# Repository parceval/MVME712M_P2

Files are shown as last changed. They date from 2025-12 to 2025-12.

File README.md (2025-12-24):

# MVME712M P2 Adapter Board

An open-source hardware replacement for the **Motorola MVME712M P2 Adapter**.

This board is designed to interface with Motorola VME CPU modules (such as the MVME147, MVME162, MVME167, and MVME177 series) to provide the necessary signals for the **MVME712M Transition Module**.

## Overview

The MVME712M P2 Adapter is a small passive board that plugs directly into the **P2 connector** on the VME backplane behind the CPU module. It breaks out the SCSI, Serial, and Centronics signals to a 50-pin header (or specific cable) that then connects to the MVME712M bulkhead/transition module.

This repository contains the KiCad design files to manufacture a modern replacement for the original Motorola part, which is often difficult to find or expensive on the used market.

## Hardware Features

* **Form Factor:** Standard VME P2 adapter dimensions.
* **Connectors:** * 96-pin DIN 41612 (Connector for VME P2 backplane).
* High-density or IDC headers for connection to the MVME712M transition board.

* **Compatibility:** Designed for use with Motorola MVME modules and the MVME712 series transition boards.
* **Passive Design:** No active components required; uses direct signal routing according to original Motorola specifications.

## Project Structure

```text
├── gerber/    # Gerbers, Drill files
└── docs/      # Pinout diagrams and reference manuals

```

## Compatibility List

This adapter is typically required for the following Motorola CPU boards when using an MVME712M transition module:

* MVME147
* MVME162 / MVME162P
* MVME167
* MVME172
* MVME177

## Usage

1. **Fabrication:** Use the provided Gerber files in the `Manufacturing/` folder to order PCBs (standard 1.6mm FR4, 1oz copper is sufficient).
2. **Assembly:** Solder the 96-pin DIN 41612 connector (Female/Socket) and the appropriate shrouded headers.
3. **Installation:** * Power down the VME chassis.
* Plug the adapter onto the **P2 pins** on the back of the backplane, directly behind your CPU module.
* Connect the internal ribbon cable from the adapter to your MVME712M transition module.

## License

This project is released under the [CERN Open Hardware Licence](https://cern-ohl.web.cern.ch/)

## Disclaimer

This is a community-driven project. While every effort has been made to ensure accuracy based on original documentation, use this hardware at your own risk. The author is not responsible for any damage to vintage VME equipment.

---

*Created by [parceval*](https://github.com/parceval)

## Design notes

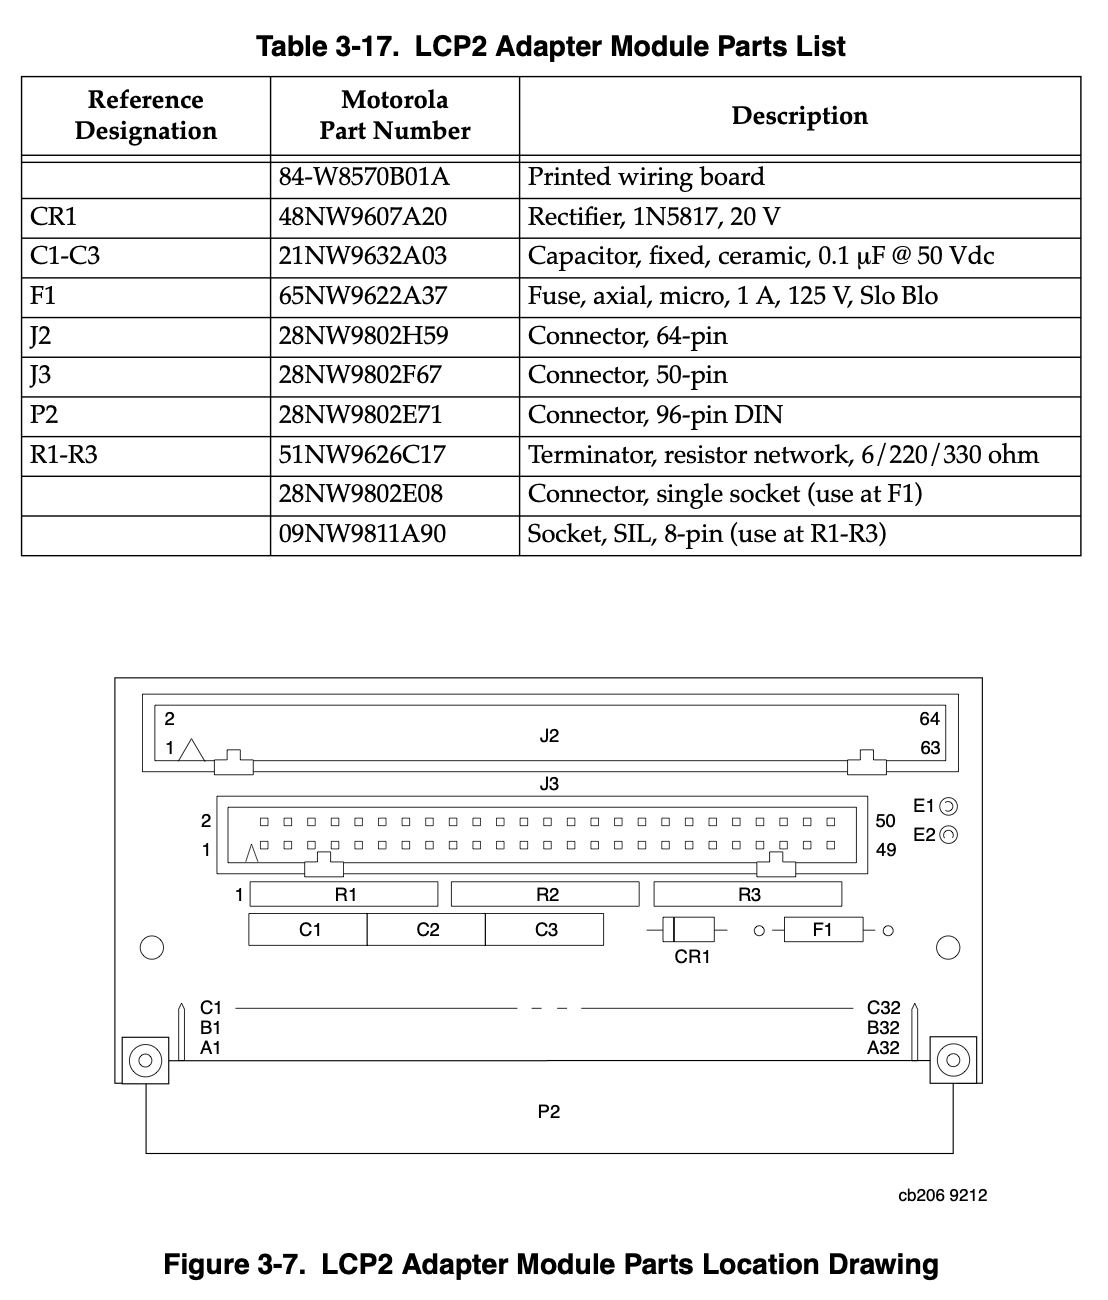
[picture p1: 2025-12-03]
docs/Screenshot_2025-11-25_at_12.06.32.png

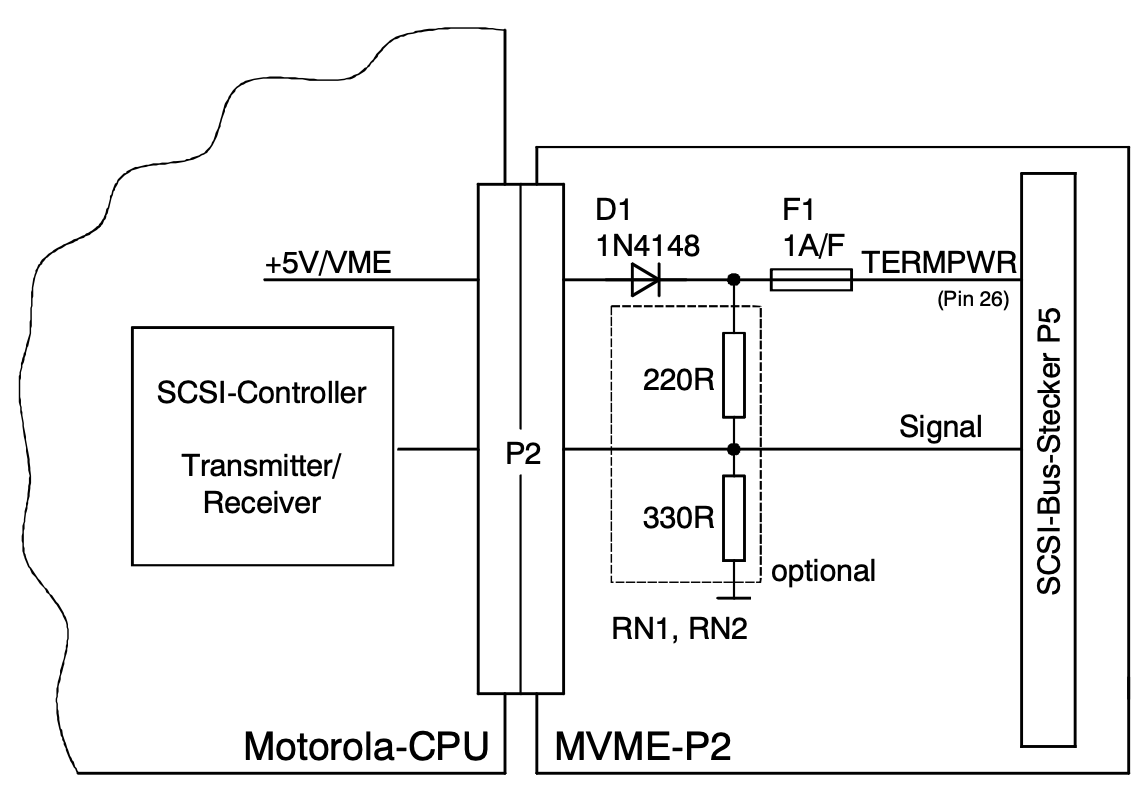
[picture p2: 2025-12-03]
docs/Screenshot_2025-11-25_at_11.56.40.png

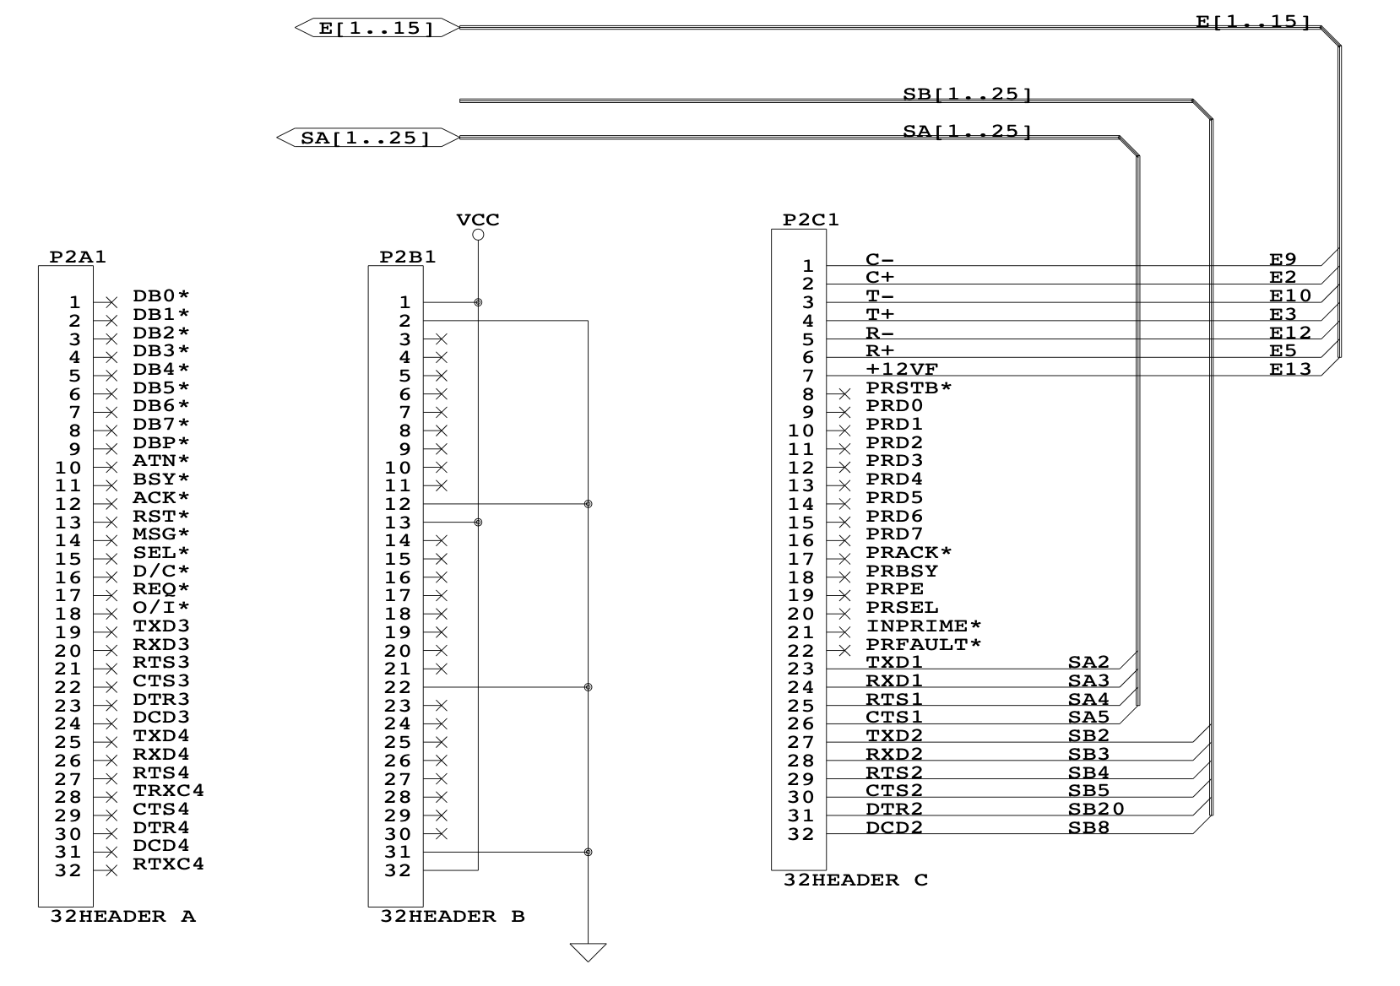
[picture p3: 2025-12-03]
docs/Screenshot_2025-11-25_at_12.11.03.png

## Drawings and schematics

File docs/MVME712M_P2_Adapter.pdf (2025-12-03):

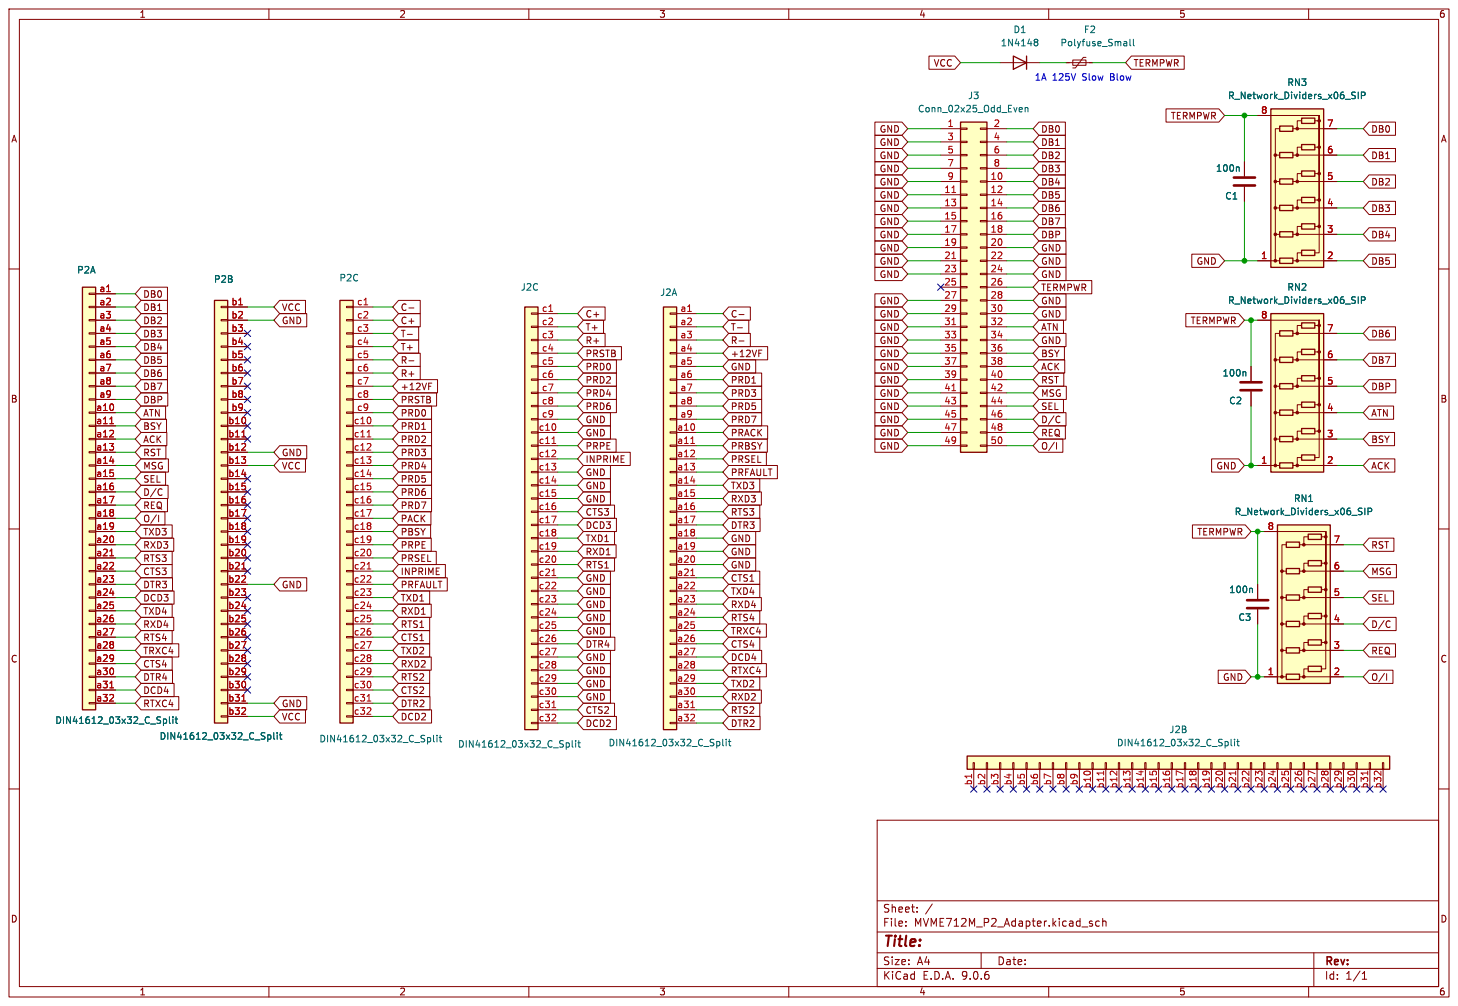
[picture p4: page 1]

Id: 1/1 Title: File: MVME712M_P2_Adapter.kicad_sch Sheet: /

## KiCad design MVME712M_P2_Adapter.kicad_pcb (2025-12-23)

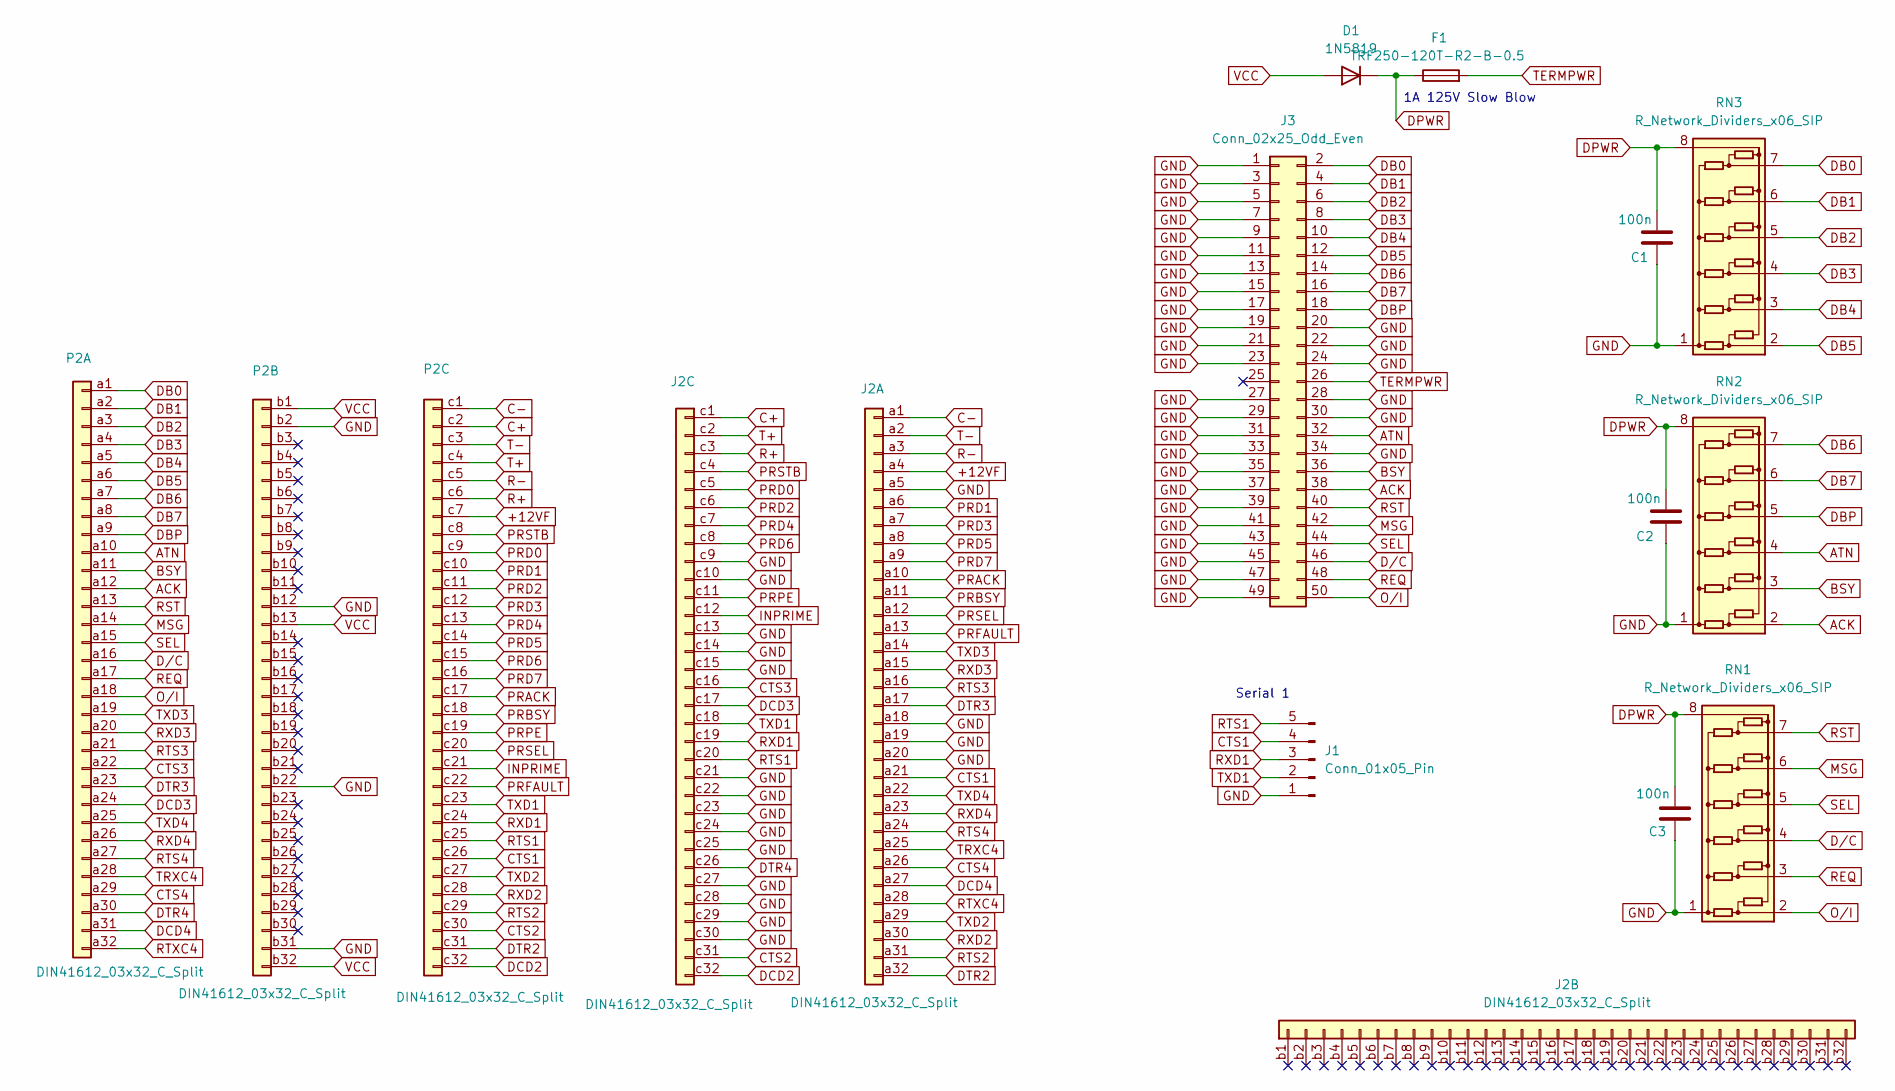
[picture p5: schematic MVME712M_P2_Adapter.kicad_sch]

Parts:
C1, C2, C3: 100n; C_Disc_D3.0mm_W1.6mm_P2.50mm
D1: 1N5819; D_DO-35_SOD27_P7.62mm_Horizontal
F1: TRF250-120T-R2-B-0.5; Fuse_Bourns_MF-RG500
J1: Conn_01x05_Pin; PinHeader_1x05_P2.54mm_Vertical
J2: DIN41612_03x32_C_Split; DIN41612_R_3x32_Male_Vertical_THT
J3: Conn_02x25_Odd_Even; IDC-Header_2x25_P2.54mm_Vertical
P2: DIN41612_03x32_C_Split; DIN41612_R_3x32_Female_Horizontal_THT
RN1, RN2, RN3: R_Network_Dividers_x06_SIP; R_Array_SIP8

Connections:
+12VF: J2.a4, P2.c7
ACK: J3.38, P2.a12, RN2.2 (R1)
ATN: J3.32, P2.a10, RN2.4 (R3)
BSY: J3.36, P2.a11, RN2.3 (R2)
C+: J2.c1, P2.c2
C-: J2.a1, P2.c1
CTS1: J1.4, J2.a21, P2.c26
CTS2: J2.c31, P2.c30
CTS3: J2.c16, P2.a22
CTS4: J2.a26, P2.a29
DB0: J3.2, P2.a1, RN3.7 (R6)
DB1: J3.4, P2.a2, RN3.6 (R5)
DB2: J3.6, P2.a3, RN3.5 (R4)
DB3: J3.8, P2.a4, RN3.4 (R3)
DB4: J3.10, P2.a5, RN3.3 (R2)
DB5: J3.12, P2.a6, RN3.2 (R1)
DB6: J3.14, P2.a7, RN2.7 (R6)
DB7: J3.16, P2.a8, RN2.6 (R5)
DBP: J3.18, P2.a9, RN2.5 (R4)
DCD2: J2.c32, P2.c32
DCD3: J2.c17, P2.a24
DCD4: J2.a27, P2.a31
DPWR: C1.1, C2.1, C3.1, D1.1 (K), F1.1, RN1.8 (COM2), RN2.8 (COM2), RN3.8 (COM2)
DTR2: J2.a32, P2.c31
DTR3: J2.a17, P2.a23
DTR4: J2.c26, P2.a30
D/C: J3.46, P2.a16, RN1.4 (R3)
GND: C1.2, C2.2, C3.2, J1.1, J2.a5, J2.a18, J2.a19, J2.a20, J2.c9, J2.c10, J2.c13, J2.c14, J2.c15, J2.c21, J2.c22, J2.c23, J2.c24, J2.c25, J2.c27, J2.c28, J2.c29, J2.c30, J3.1, J3.3, J3.5, J3.7, J3.9, J3.11, J3.13, J3.15, J3.17, J3.19, J3.20, J3.21, J3.22, J3.23, J3.24, J3.27, J3.28, J3.29, J3.30, J3.31, J3.33, J3.34, J3.35, J3.37, J3.39, J3.41, J3.43, J3.45, J3.47, J3.49, P2.b2, P2.b12, P2.b22, P2.b31, RN1.1 (COM1), RN2.1 (COM1), RN3.1 (COM1)
INPRIME: J2.c12, P2.c21
MSG: J3.42, P2.a14, RN1.6 (R5)
O/I: J3.50, P2.a18, RN1.2 (R1)
PRACK: J2.a10, P2.c17
PRBSY: J2.a11, P2.c18
PRD0: J2.c5, P2.c9
PRD1: J2.a6, P2.c10
PRD2: J2.c6, P2.c11
PRD3: J2.a7, P2.c12
PRD4: J2.c7, P2.c13
PRD5: J2.a8, P2.c14
PRD6: J2.c8, P2.c15
PRD7: J2.a9, P2.c16
PRFAULT: J2.a13, P2.c22
PRPE: J2.c11, P2.c19
PRSEL: J2.a12, P2.c20
PRSTB: J2.c4, P2.c8
R+: J2.c3, P2.c6
R-: J2.a3, P2.c5
REQ: J3.48, P2.a17, RN1.3 (R2)
RST: J3.40, P2.a13, RN1.7 (R6)
RTS1: J1.5, J2.c20, P2.c25
RTS2: J2.a31, P2.c29
RTS3: J2.a16, P2.a21
RTS4: J2.a24, P2.a27
RTXC4: J2.a28, P2.a32
RXD1: J1.3, J2.c19, P2.c24
RXD2: J2.a30, P2.c28
RXD3: J2.a15, P2.a20
RXD4: J2.a23, P2.a26
SEL: J3.44, P2.a15, RN1.5 (R4)
T+: J2.c2, P2.c4
T-: J2.a2, P2.c3
TERMPWR: F1.2, J3.26
TRXC4: J2.a25, P2.a28
TXD1: J1.2, J2.c18, P2.c23
TXD2: J2.a29, P2.c27
TXD3: J2.a14, P2.a19
TXD4: J2.a22, P2.a25
VCC: D1.2 (A), P2.b1, P2.b13, P2.b32

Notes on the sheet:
1A 125V Slow Blow
Serial 1

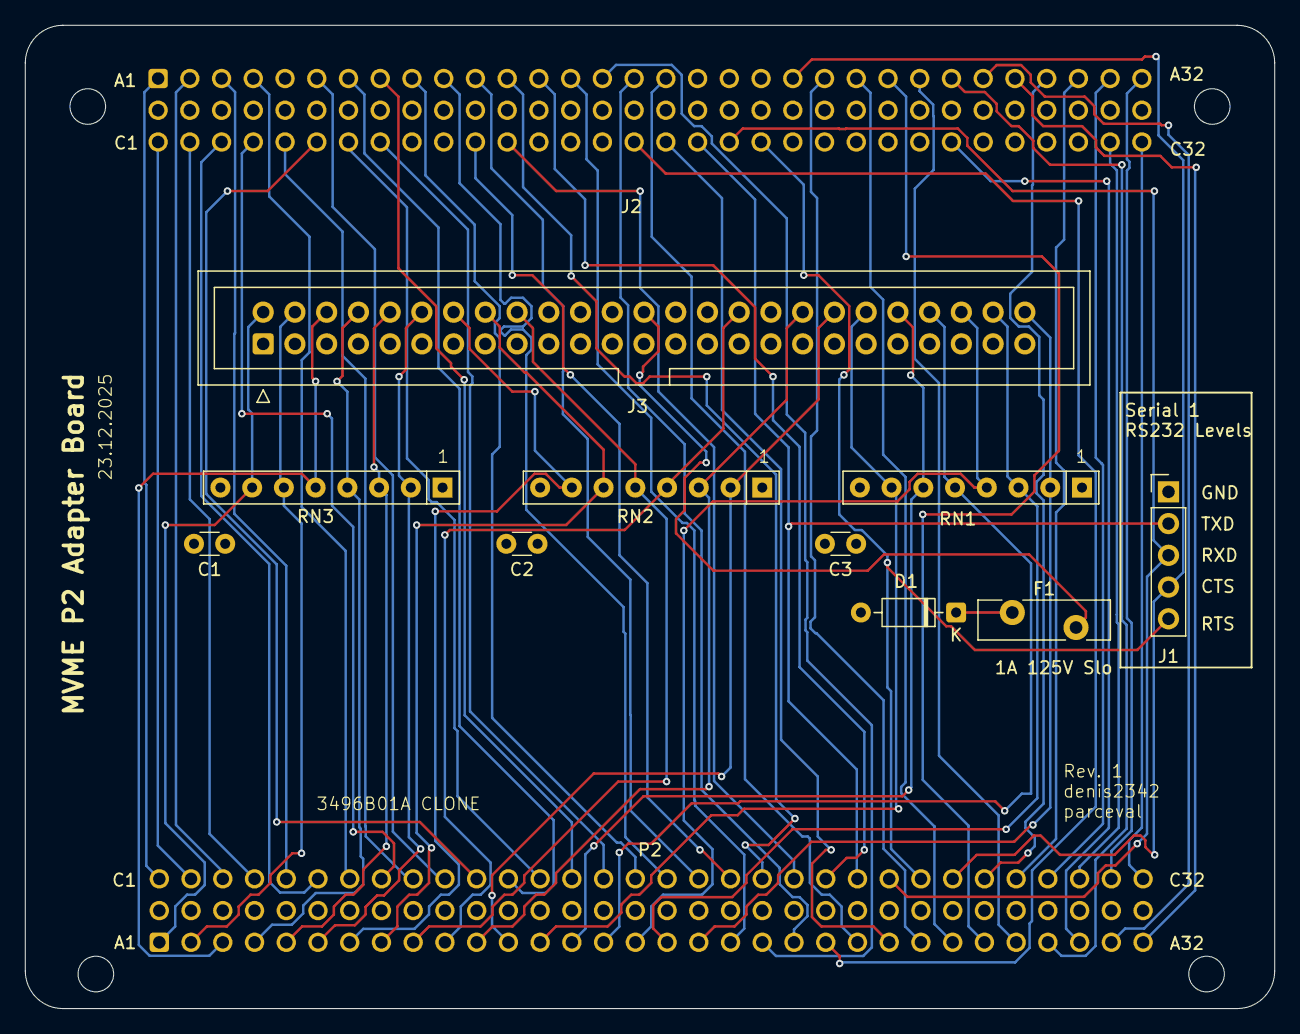
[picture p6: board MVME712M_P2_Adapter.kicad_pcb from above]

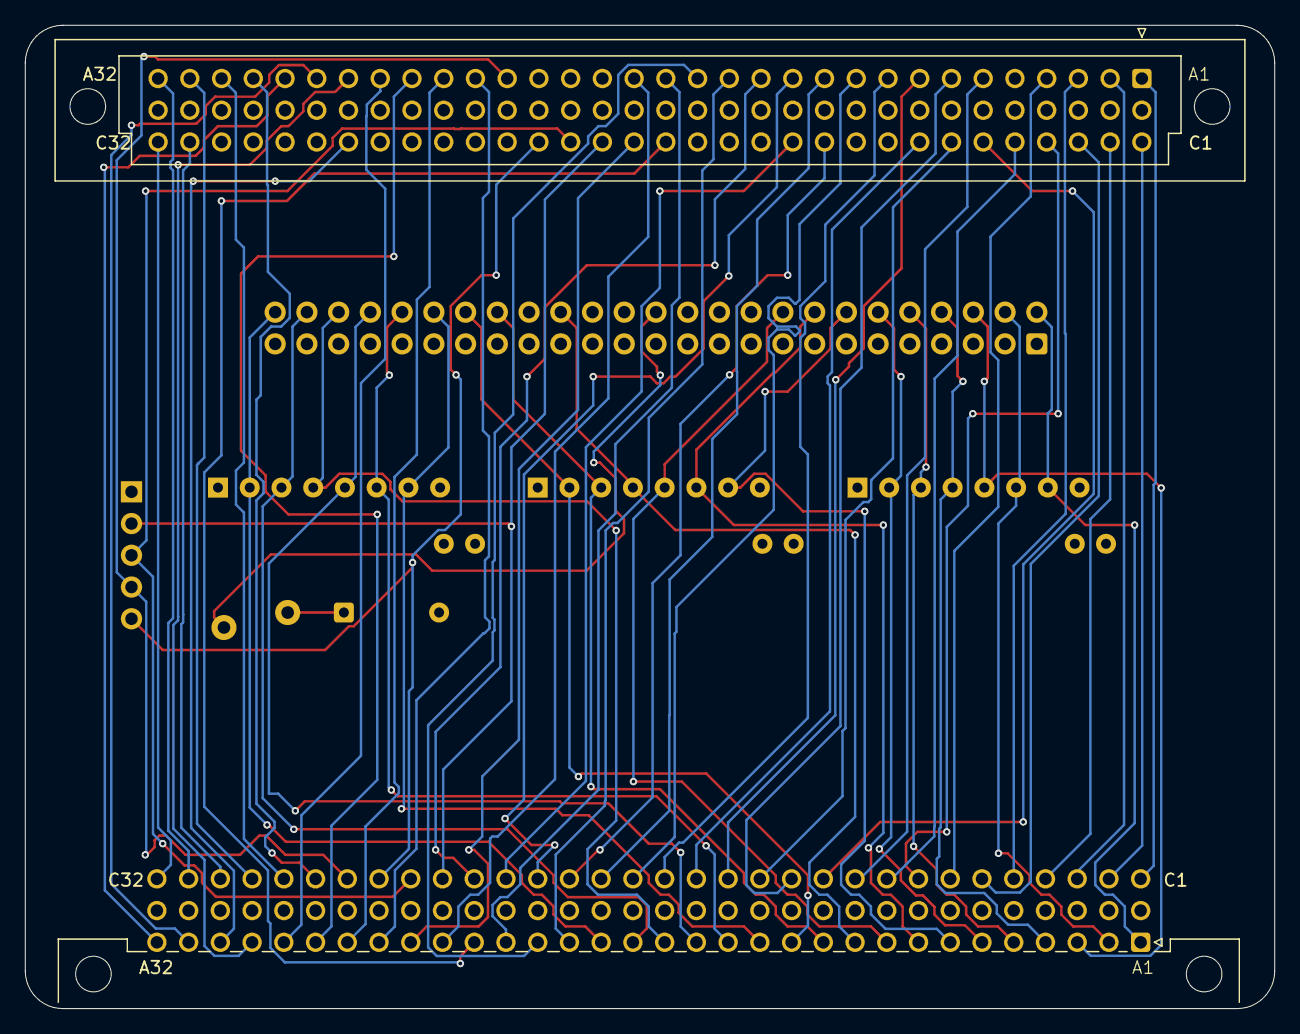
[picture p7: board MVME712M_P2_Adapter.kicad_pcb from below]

Board: 4 copper layers, 100.0 x 78.7 mm, 12 parts (2 on the bottom side), 68 nets.

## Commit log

2025-12-23 added RS232 text
    [MVME712M_P2_Adapter-B_Cu.gbr, MVME712M_P2_Adapter-B_Mask.gbr, MVME712M_P2_Adapter-B_Paste.gbr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]
2025-12-23 added RS232 text on pcb
    [MVME712M_P2_Adapter.kicad_pcb]
2025-12-24 added license file and cleanup
    [MVME712M_P2_Adapter_old.kicad_pcb]
